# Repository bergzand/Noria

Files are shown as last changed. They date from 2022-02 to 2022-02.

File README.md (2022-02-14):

# Noria Split Keyboard

The Noria keyboard is a Kyria-based split keyboard. It has 6 colums and 3 rows
with a larger thumb cluster. Like the original Kyria it has support for both 2U
and dual 1U keys for the thumbs. There are three positions for a rotary encoder
of which one can be used at a time

The PCB can be flipped and used for both the left and right variant.

The PCB has space for a SPI NOR flash chip that can be used for user
configuration settings

## Design gotchas

- *When using a rotary encoder*: The pads for the chassis pins of the rotary
  encoder overlap with the pins for the push button. When using a rotary encoder
  with a push button the chassis pads must be manually detached (a simple knife
  will do) from *both* sides of the PCB.

- The microcontroller module and the SPI NOR flash must be on the same side of
  the PCB

- To use the reset pin, the User Information Configuration Register must be
  configured to pin 0.18 of the microntroller.

- The rotary encoder pins are connected to the NFC antenna pins of the
  microcontroller. As these pins are protected by default for NFC operations and
  will not function as rotary encoder pins. These protections must be disabled
  in the NFCPINS registers of the User Information Configuration Register.

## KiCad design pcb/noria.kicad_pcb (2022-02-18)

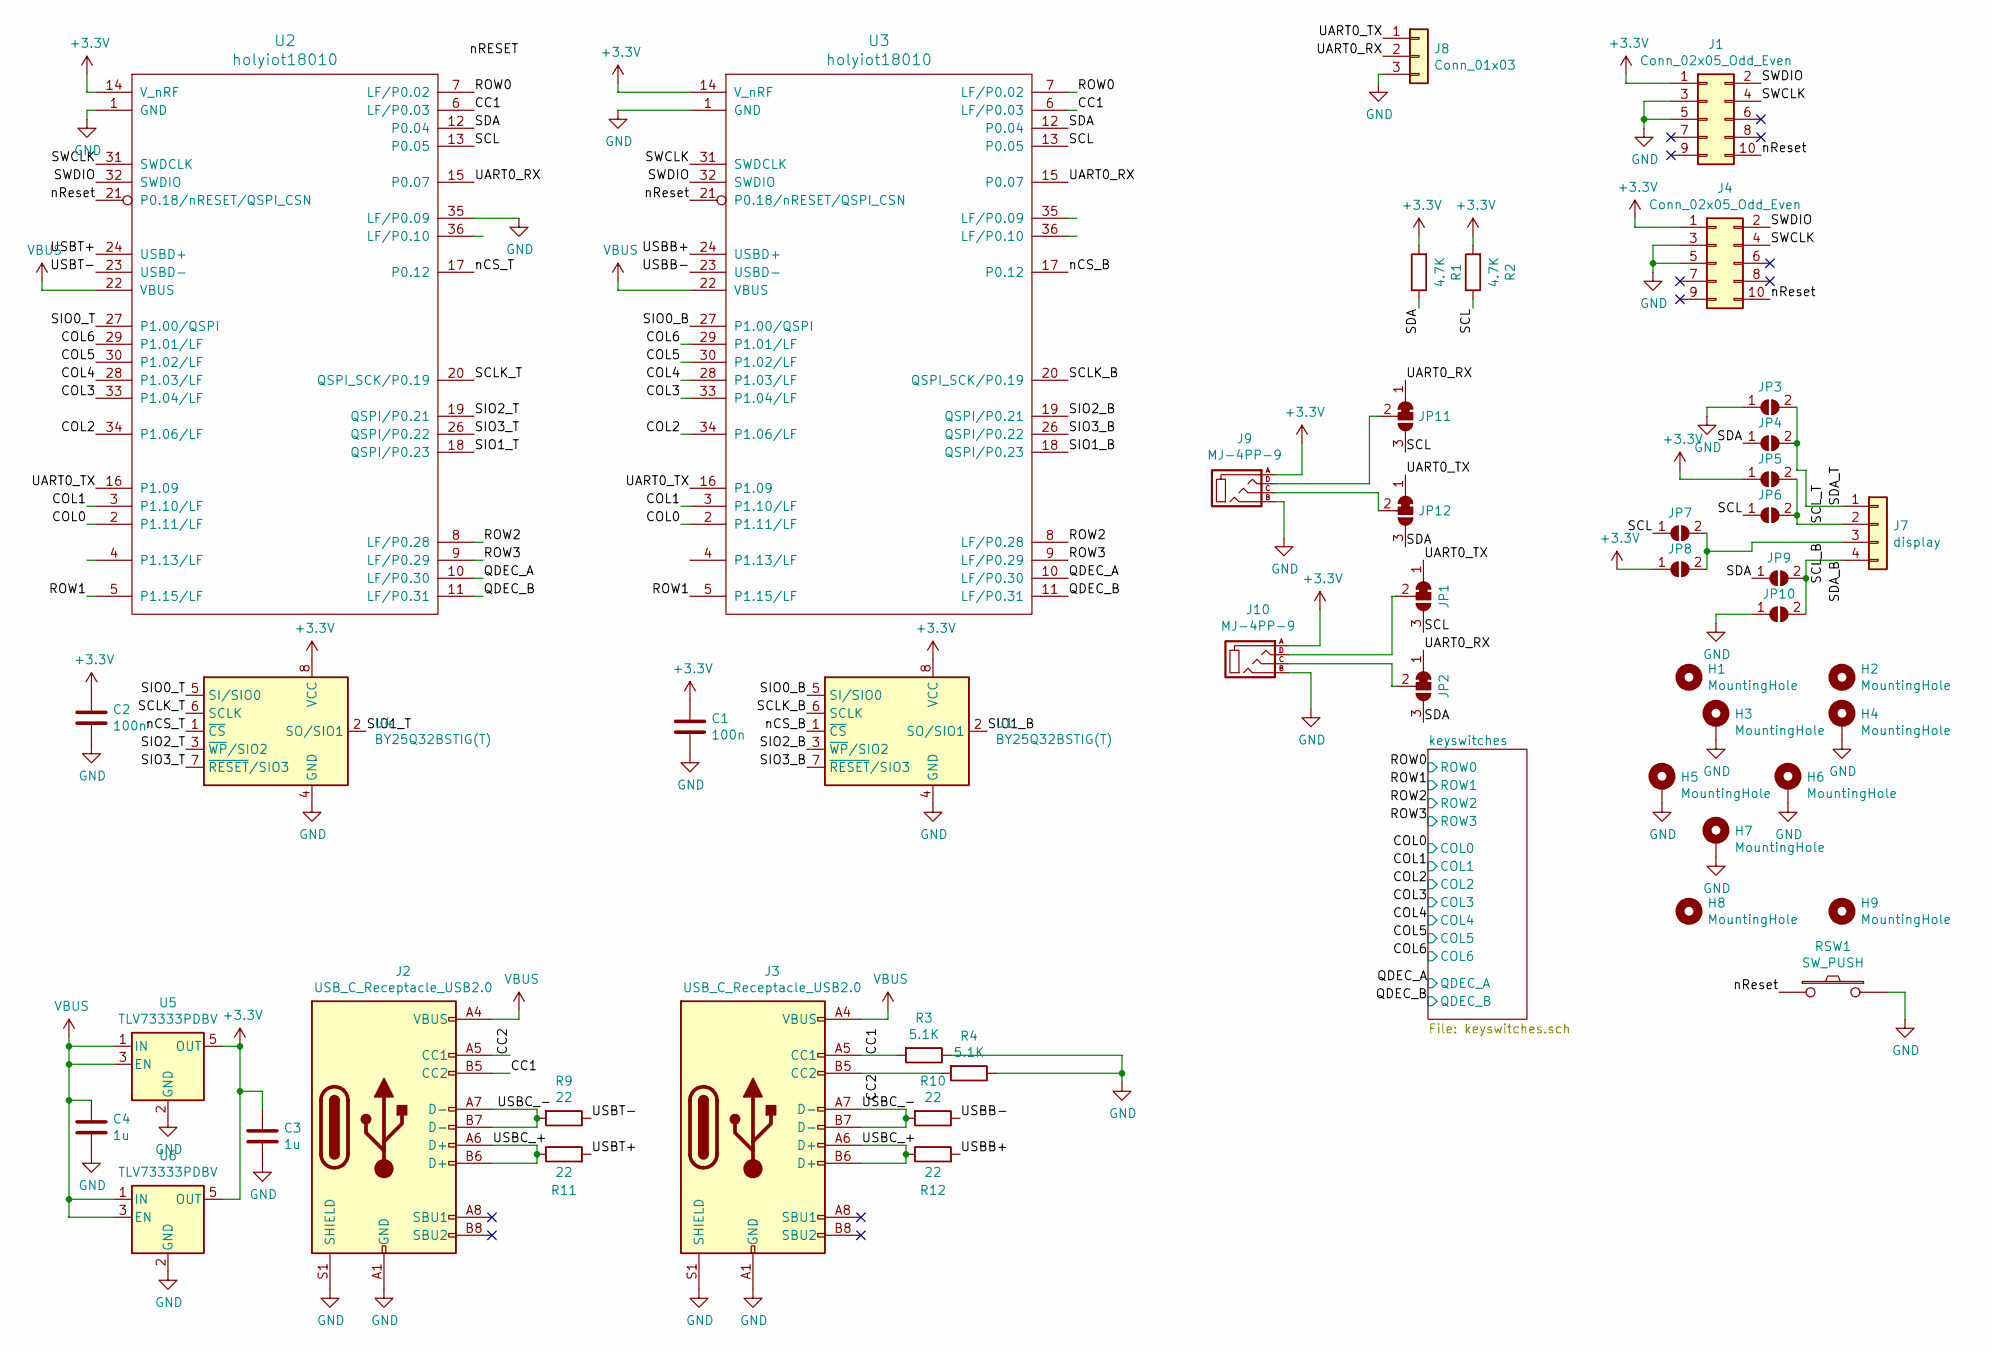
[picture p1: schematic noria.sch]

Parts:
C1, C2: 100n; C_0603_1608Metric_Pad1.08x0.95mm_HandSolder; LCSC C66501
C3, C4: 1u; C_0603_1608Metric_Pad1.08x0.95mm_HandSolder_mirror; LCSC C59782
H1, H2: MountingHole; spacer_m2
H3, H4, H5, H6, H7: MountingHole; MountingHole_3.5mm_Pad_Via
H8, H9: MountingHole; M2_Hole_TH
J1, J4: Conn_02x05_Odd_Even; PinHeader_2x05_P1.27mm_Vertical_SMD; LCSC C150517
J2, J3: USB_C_Receptacle_USB2.0; USB_C_Receptacle_HRO_TYPE-C-31-M-12; LCSC C165948
J7: display; PinHeader_1x04_P2.54mm_Vertical; LCSC C2718488
J8: Conn_01x03; PinHeader_1x03_P2.54mm_Vertical
J9, J10: MJ-4PP-9; MJ-4PP-9_1side; LCSC C136687
JP1, JP2, JP11, JP12: SolderJumper_3_Bridged12; SolderJumper-3_P1.3mm_Bridged12_Pad1.0x1.5mm
JP3, JP4, JP5, JP6, JP7, JP8, JP9, JP10: SolderJumper_2_Open; Jumper
R1, R2: 4.7K; R_0603_1608Metric_Pad0.98x0.95mm_HandSolder; LCSC C23162
R3, R4: 5.1K; R_0603_1608Metric_Pad0.98x0.95mm_HandSolder; LCSC C23186
R9, R10, R11, R12: 22; R_0603_1608Metric_Pad0.98x0.95mm_HandSolder; LCSC C23345
RSW1: SW_PUSH; ResetSW; LCSC C498307
U1, U4: BY25Q32BSTIG(T); SOP-8_3.9x4.9mm_P1.27mm; LCSC C394868
U2, U3: holyiot18010; holyiot18010_no_inner
U5, U6: TLV73333PDBV; SOT-23-5; LCSC C134139

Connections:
+3V3: C1.1, C2.1, C3.1, J1.1, J4.1, J9.A, J10.A, JP5.1 (A), JP8.1 (A), R1.2, R2.2, U1.8 (VCC), U2.14 (V_nRF), U3.14 (V_nRF), U4.8 (VCC), U5.5 (OUT), U6.5 (OUT)
/CC1: J2.B5 (CC2), J3.A5 (CC1), R3.2, U2.6 (LF/P0.03), U3.6 (LF/P0.03)
/CC2: J2.A5 (CC1), J3.B5 (CC2), R4.2
/COL0: U2.2 (P1.11/LF), U3.2 (P1.11/LF); also elsewhere on the board
/COL1: U2.3 (P1.10/LF), U3.3 (P1.10/LF); also elsewhere on the board
/COL2: U2.34 (P1.06/LF), U3.34 (P1.06/LF); also elsewhere on the board
/COL3: U2.33 (P1.04/LF), U3.33 (P1.04/LF); also elsewhere on the board
/COL4: U2.28 (P1.03/LF), U3.28 (P1.03/LF); also elsewhere on the board
/COL5: U2.30 (P1.02/LF), U3.30 (P1.02/LF); also elsewhere on the board
/COL6: U2.29 (P1.01/LF), U3.29 (P1.01/LF); also elsewhere on the board
/QDEC_A: U2.10 (LF/P0.30), U3.10 (LF/P0.30); also elsewhere on the board
/QDEC_B: U2.11 (LF/P0.31), U3.11 (LF/P0.31); also elsewhere on the board
/ROW0: U2.7 (LF/P0.02), U3.7 (LF/P0.02); also elsewhere on the board
/ROW1: U2.5 (P1.15/LF), U3.5 (P1.15/LF); also elsewhere on the board
/ROW2: U2.8 (LF/P0.28), U3.8 (LF/P0.28); also elsewhere on the board
/ROW3: U2.9 (LF/P0.29), U3.9 (LF/P0.29); also elsewhere on the board
/SCL: JP1.3 (B), JP6.1 (A), JP7.1 (A), JP11.3 (B), R2.1, U2.13 (P0.05), U3.13 (P0.05)
/SCLK_B: U1.6 (SCLK), U3.20 (QSPI_SCK/P0.19)
/SCLK_T: U2.20 (QSPI_SCK/P0.19), U4.6 (SCLK)
/SCL_B: J7.3, JP7.2 (B), JP8.2 (B)
/SCL_T: J7.2, JP5.2 (B), JP6.2 (B)
/SDA: JP2.3 (B), JP4.1 (A), JP9.1 (A), JP12.3 (B), R1.1, U2.12 (P0.04), U3.12 (P0.04)
/SDA_B: J7.4, JP9.2 (B), JP10.2 (B)
/SDA_T: J7.1, JP3.2 (B), JP4.2 (B)
/SIO0_B: U1.5 (SI/SIO0), U3.27 (P1.00/QSPI)
/SIO0_T: U2.27 (P1.00/QSPI), U4.5 (SI/SIO0)
/SIO1_B: U1.2 (SO/SIO1), U3.18 (QSPI/P0.23)
/SIO1_T: U2.18 (QSPI/P0.23), U4.2 (SO/SIO1)
/SIO2_B: U1.3 (~WP~/SIO2), U3.19 (QSPI/P0.21)
/SIO2_T: U2.19 (QSPI/P0.21), U4.3 (~WP~/SIO2)
/SIO3_B: U1.7 (~RESET~/SIO3), U3.26 (QSPI/P0.22)
/SIO3_T: U2.26 (QSPI/P0.22), U4.7 (~RESET~/SIO3)
/SWCLK: J1.4, J4.4, U2.31 (SWDCLK), U3.31 (SWDCLK)
/SWDIO: J1.2, J4.2, U2.32 (SWDIO), U3.32 (SWDIO)
/UART0_RX: J8.2, JP2.1 (A), JP11.1 (A), U2.15 (P0.07), U3.15 (P0.07)
/UART0_TX: J8.1, JP1.1 (A), JP12.1 (A), U2.16 (P1.09), U3.16 (P1.09)
/USBB+: R12.2, U3.24 (USBD+)
/USBB-: R10.1, U3.23 (USBD-)
/USBC_+: J2.A6 (D+), J2.B6 (D+), J3.A6 (D+), J3.B6 (D+), R11.1, R12.1
/USBC_-: J2.A7 (D-), J2.B7 (D-), J3.A7 (D-), J3.B7 (D-), R9.2, R10.2
/USBT+: R11.2, U2.24 (USBD+)
/USBT-: R9.1, U2.23 (USBD-)
/nCS_B: U1.1 (~CS), U3.17 (P0.12)
/nCS_T: U2.17 (P0.12), U4.1 (~CS)
/nReset: J1.10, J4.10, RSW1.1, U2.21 (P0.18/nRESET/QSPI_CSN), U3.21 (P0.18/nRESET/QSPI_CSN)
GND: C1.2, C2.2, C3.2, C4.2, H3.1, H4.1, H5.1, H6.1, H7.1, J1.3, J1.5, J2.A1 (GND), J2.A12 (GND), J2.B1 (GND), J2.B12 (GND), J2.S1 (SHIELD), J3.A1 (GND), J3.A12 (GND), J3.B1 (GND), J3.B12 (GND), J3.S1 (SHIELD), J4.3, J4.5, J8.3, J9.B, J10.B, JP3.1 (A), JP10.1 (A), R3.1, R4.1, RSW1.2, U1.4 (GND), U2.1 (GND), U2.35 (LF/P0.09), U3.1 (GND), U3.36 (LF/P0.10), U4.4 (GND), U5.2 (GND), U6.2 (GND); also elsewhere on the board
unnamed: J9.C, JP12.2 (C)
unnamed: J9.D, JP11.2 (C)
unnamed: J10.C, JP2.2 (C)
unnamed: J10.D, JP1.2 (C)
VBUS: C4.1, J2.A4 (VBUS), J2.A9 (VBUS), J2.B4 (VBUS), J2.B9 (VBUS), J3.A4 (VBUS), J3.A9 (VBUS), J3.B4 (VBUS), J3.B9 (VBUS), U2.22 (VBUS), U3.22 (VBUS), U5.1 (IN), U5.3 (EN), U6.1 (IN), U6.3 (EN)

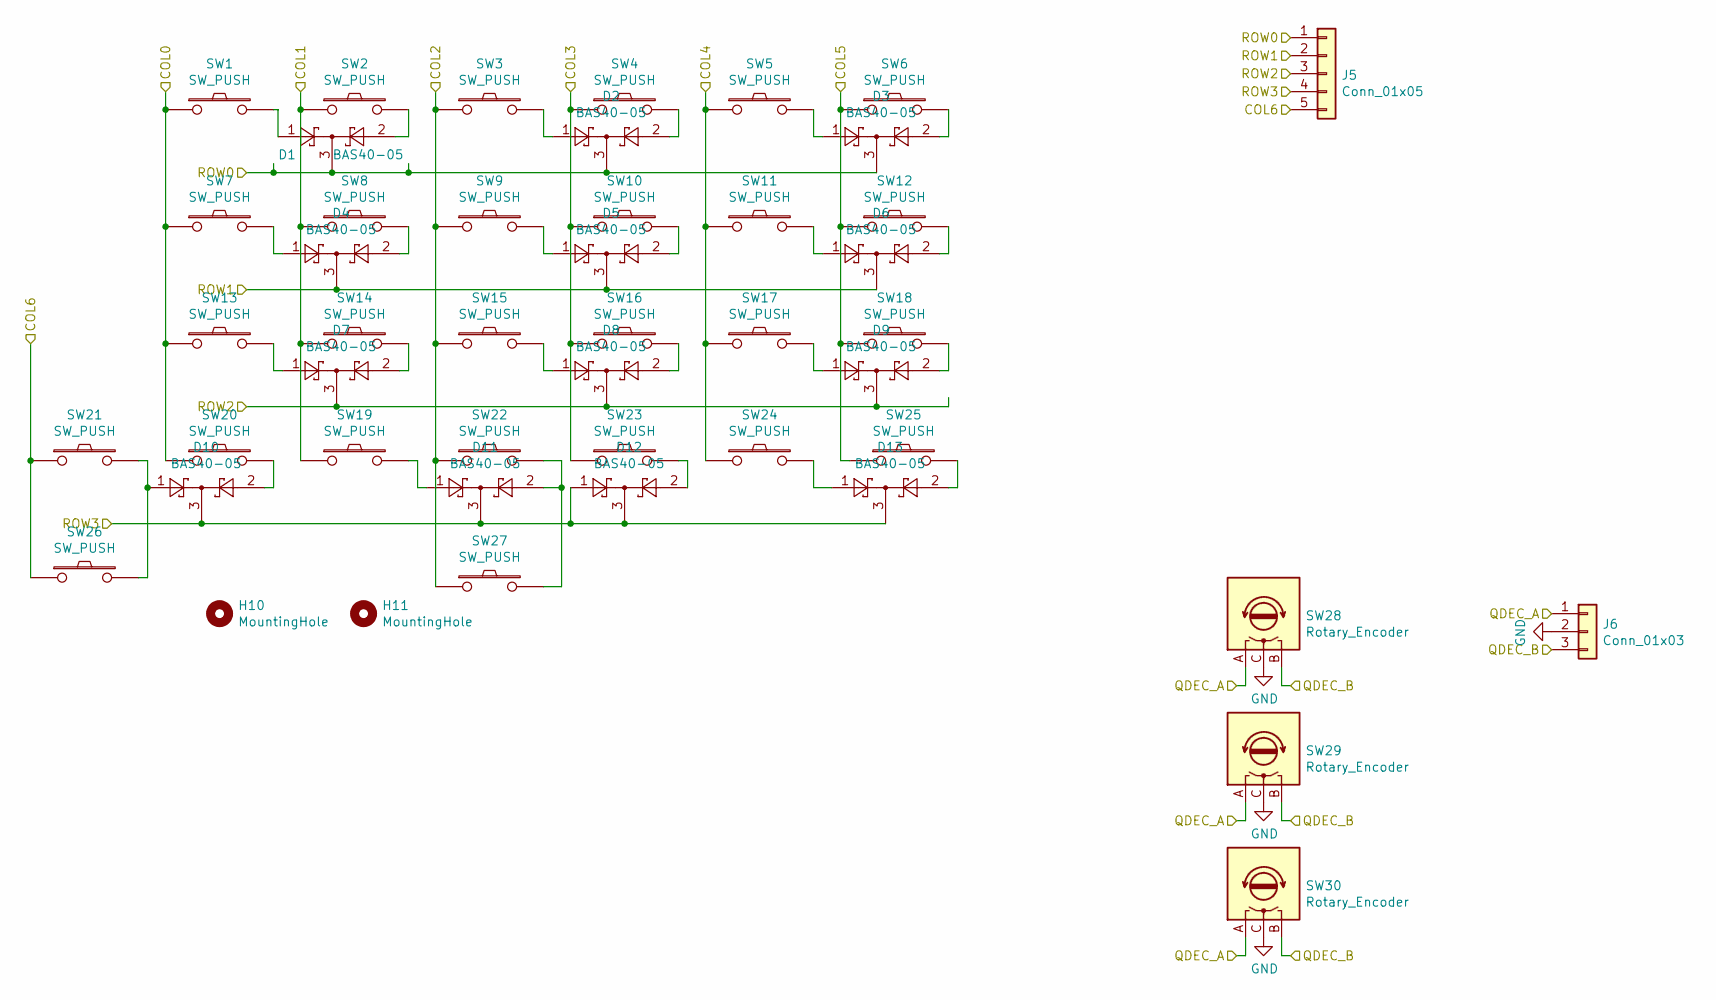
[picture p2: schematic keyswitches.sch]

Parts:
D1, D2, D3, D4, D5, D6, D7, D8, D9, D10, D11, D12, D13: BAS40-05; SOT-23_mirror; LCSC C699088
H10, H11: MountingHole; Stabilizer_MX_2u
J5: Conn_01x05; PinHeader_1x05_P2.54mm_Vertical
J6: Conn_01x03; PinHeader_1x03_P2.54mm_Vertical
SW1, SW2, SW3, SW4, SW5, SW6, SW7, SW8, SW9, SW10, SW11, SW12, SW13, SW14, SW15, SW16, SW17, SW18, SW19, SW20, SW21, SW22, SW23, SW24, SW25: SW_PUSH; MX_ALPS_PG1350_noLed
SW26, SW27: SW_PUSH; MX_ALPS_reduced
SW28, SW29, SW30: Rotary_Encoder; RotaryEncoder_Alps_EC11E_Vertical_H20mm

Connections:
/COL0: SW1.1, SW7.1, SW13.1, SW20.1; also elsewhere on the board
/COL1: SW2.1, SW8.1, SW14.1, SW19.1; also elsewhere on the board
/COL2: SW3.1, SW9.1, SW15.1, SW22.1, SW27.1; also elsewhere on the board
/COL3: SW4.1, SW10.1, SW16.1, SW23.1; also elsewhere on the board
/COL4: SW5.1, SW11.1, SW17.1, SW24.1; also elsewhere on the board
/COL5: SW6.1, SW12.1, SW18.1, SW25.1; also elsewhere on the board
/COL6: J5.5, SW21.1, SW26.1; also elsewhere on the board
/QDEC_A: J6.1, SW28.A, SW29.A, SW30.A; also elsewhere on the board
/QDEC_B: J6.3, SW28.B, SW29.B, SW30.B; also elsewhere on the board
/ROW0: D1.3, D2.3, D3.3, J5.1; also elsewhere on the board
/ROW1: D4.3, D5.3, D6.3, J5.2; also elsewhere on the board
/ROW2: D7.3, D8.3, D9.3, J5.3; also elsewhere on the board
/ROW3: D10.3, D11.3, D12.1, D12.3, D13.3, J5.4; also elsewhere on the board
GND: J6.2, SW28.C, SW29.C, SW30.C; also elsewhere on the board
unnamed: D1.1, SW1.2
unnamed: D1.2, SW2.2
unnamed: D2.1, SW3.2
unnamed: D2.2, SW4.2
unnamed: D3.1, SW5.2
unnamed: D3.2, SW6.2
unnamed: D4.1, SW7.2
unnamed: D4.2, SW8.2
unnamed: D5.1, SW9.2
unnamed: D5.2, SW10.2
unnamed: D6.1, SW11.2
unnamed: D6.2, SW12.2
unnamed: D7.1, SW13.2
unnamed: D7.2, SW14.2
unnamed: D8.1, SW15.2
unnamed: D8.2, SW16.2
unnamed: D9.1, SW17.2
unnamed: D9.2, SW18.2
unnamed: D10.1, SW21.2, SW26.2
unnamed: D10.2, SW20.2
unnamed: D11.1, SW19.2
unnamed: D11.2, SW22.2, SW27.2
unnamed: D12.2, SW23.2
unnamed: D13.1, SW24.2
unnamed: D13.2, SW25.2

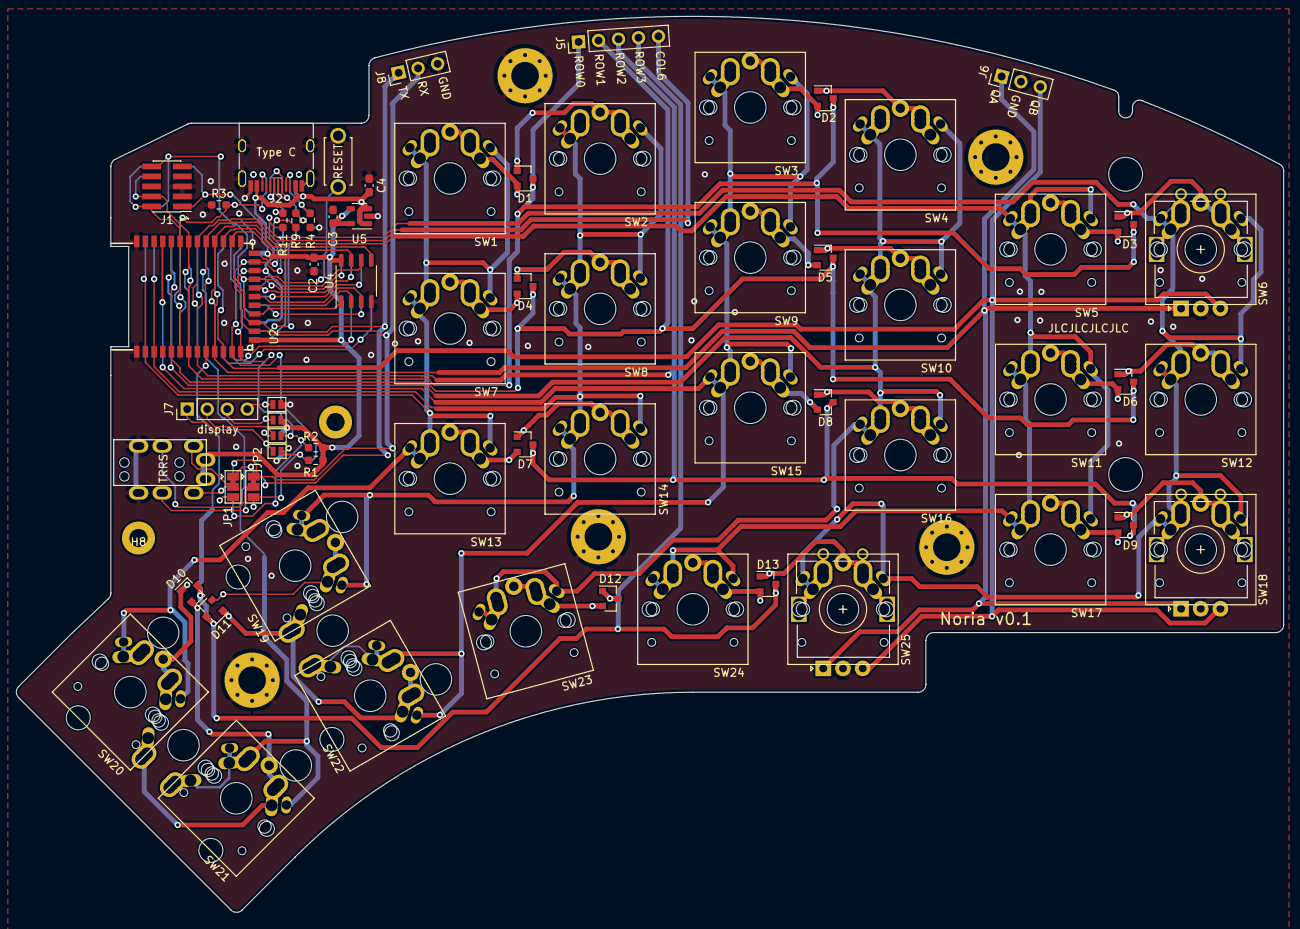
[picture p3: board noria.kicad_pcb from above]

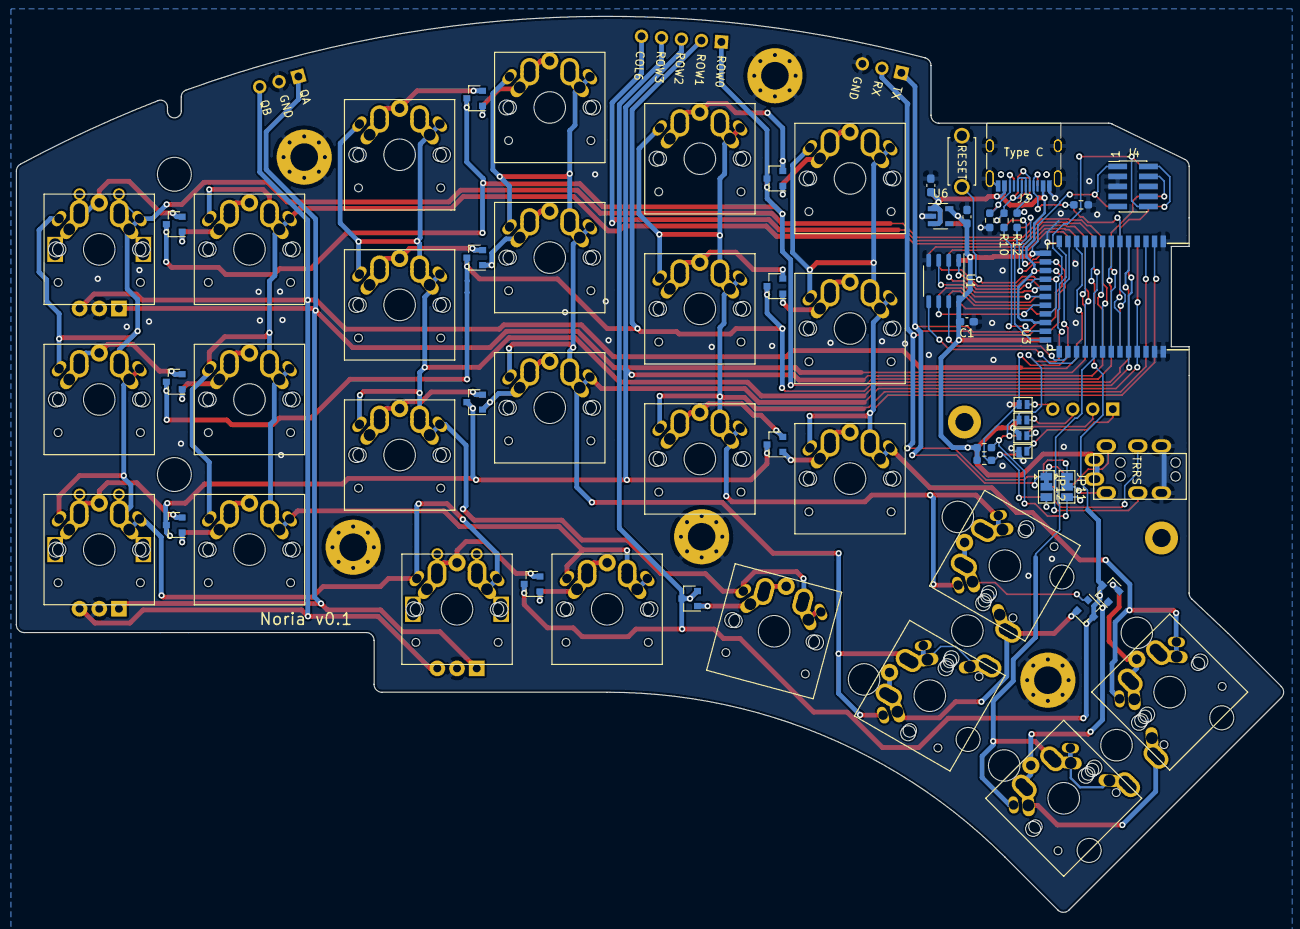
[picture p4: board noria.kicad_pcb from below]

Board: 2 copper layers, 160.8 x 113.7 mm, 95 parts (27 on the bottom side), 76 nets.

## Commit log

2021-10-14 Initial commit of Noria layout
    [noria.kicad_pcb, noria.sch]
2021-10-16 Add keyswitches footprints
2021-10-21 Finished iteration 1
    [keyswitches.sch, noria.kicad_pcb, noria.sch]
2022-02-18 Update to latest design
    [noria.kicad_pcb, noria.sch]
2022-02-18 And another update
    [keyswitches.sch, noria.kicad_pcb]
2022-02-18 Add kicad gitignore
